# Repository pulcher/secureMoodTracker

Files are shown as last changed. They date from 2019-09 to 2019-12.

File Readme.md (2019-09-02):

# Secure Mood Tracker

## Purpose

To win a contest? [insert link to Hackster.io contest]

Not really.  Well, maybe?  It certainly was the initiating incident for this project.  

The project is an example of how to not only obtain telemetry data with an MT3620 based Azure Sphere device, but also how to consume and visualize the data in an extremly secure manner.

The project will track the mood of the office and report it to the cloud for further analysis.  

The project will have the following features:

* Display inviting a passer by to indicate their current mood by pressing one of 3 buttons.
* Good: Press the Green button.
* Average: Press the Yellow button.
* Bad(less than average, etc...): Press the Red button.
* The buttons will flash randomly to attrack attention
* There will be a proximity detector on the device to detect when there is motion in front of the device.  That way we can have some sort of data of how many times a person was in range of the device and a button was or was not pushed.
* Current temperature and humidity.  (Current IoT international by laws mandate this type of measurement.)
* Will also provide any other builtin sensor data that may be useful when the data is further analyzed.

## Design Considerations

* Must be created using the Azure Sphere MT3620 Starter Kit <https://www.element14.com/community/community/designcenter/azure-sphere-starter-kits>
* Device must be secure from end to end.

## Challenges

There are several challenges in this design.

### Not enough GPIO on the dev board

There are a number of GPIO pins on the Azure Sphere module, most of them are not directly accessible.

The dev board is setup to use the mikroBUS Click Modules.  It has a number of buttons, LEDS, Grove connectors, and more that consume most if not all of the easily available GPIO pins.

I have decided to solve that problem with the addition of a MCP23017 GPIO extender.  This gives me and additional 16 pins of GPIO, which is way more than required.

There is a Click module that holds MCP23017, I decided that using a generica module would be a more educational experience.  

There is a also a problem with libraries to access the expanded GPIO.  They don't currently exist in the Azure Sphere eco system.  There are libraries for the Click module using the Avent development system, but none specifically for the Azure Sphere module.

I the development board team has provided a reference application that accesses the various I2C modules on the dev board.  I plan on using that as a pattern to build up my own libarary to operate the MCP23017 over I2C.

### Attracking people to the device

The lights in the buttons can be controlled independently of the switch activation.  The lights will flash in various patterns to attract attention.

The device will be placed in a high traffic area.

The display will rotate with with data and instructions.

When the proximity sensor goes active the instructions will be display.

## Requirements

### Software

* Azure subscription
* Visual Studio 2019 Community Edition
* See the startup stuff...

### Hardware

* MT3620 Developement Board
* Red LED Mini Arcade Button http://adafru.it/3430
* Yellow LED Mini Arcade Button http://adafru.it/3430
* Green LED Mini Arcade Button http://adafru.it/3430
* MCP23017 breakout board
* 3 x 2N222 NPN transistors
* 3 x 220 ohm resistors
* USB Micro b jack to USB micro b plug http://adafru.it/5217
* Mini breadboard
* 3D printed case
* Power supply withe a micro b connector

### Tools

* Soldering Iron
* Digital Multimeter
* Jumper wires

## Build

### Software Setup

### Setup the MT3620

### Prep the buttons

### Connect up the MCP23017

### Connect the Oled

### Main code

### Print the enclosure

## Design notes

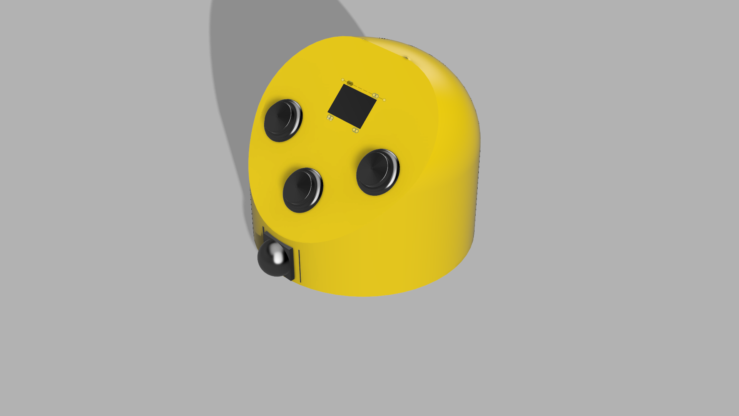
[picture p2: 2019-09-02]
Case Designs/c v2.png

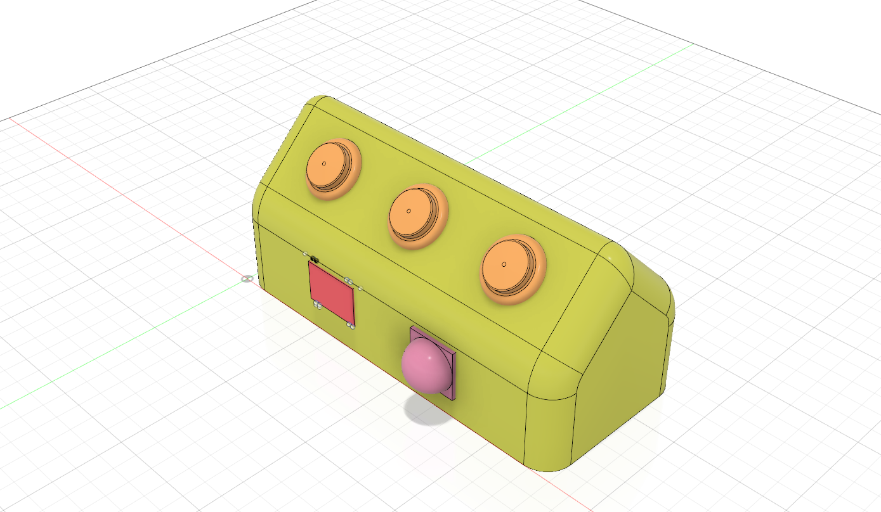
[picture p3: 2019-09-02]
Case Designs/b v2.png

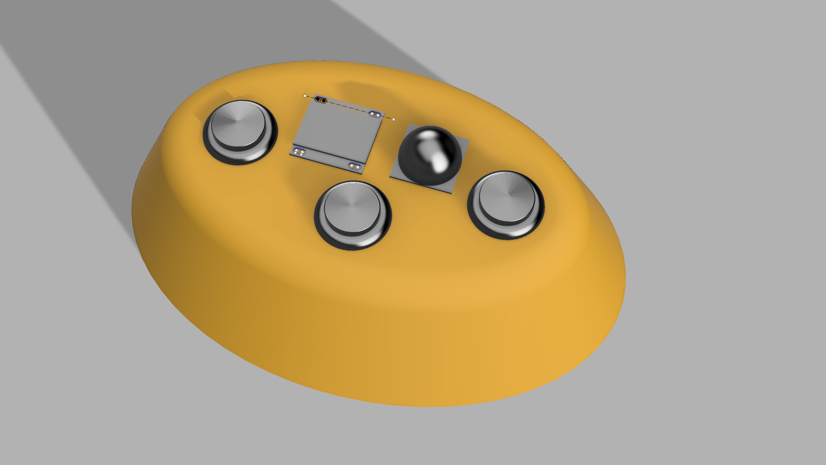
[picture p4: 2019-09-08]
Case Designs/f v1.png

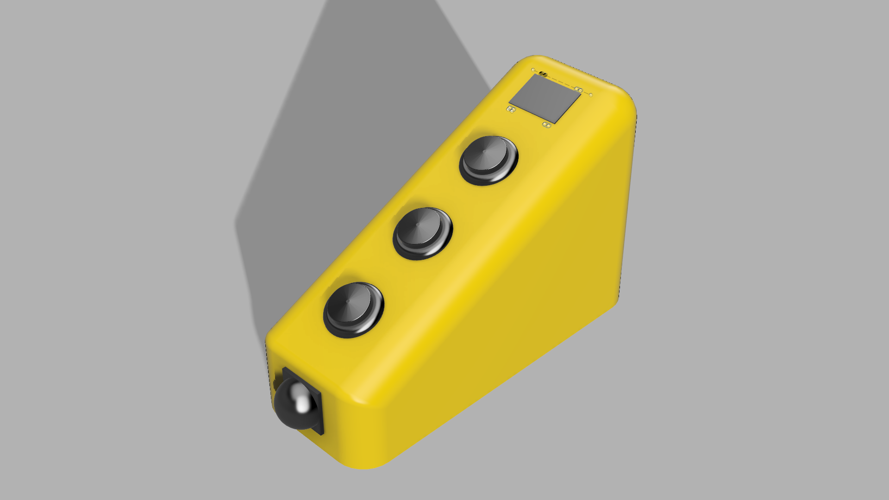
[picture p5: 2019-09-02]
Case Designs/d v2.png

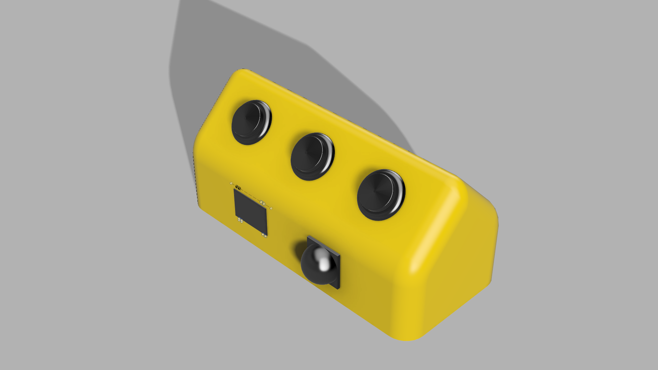
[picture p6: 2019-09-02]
Case Designs/b v3.png

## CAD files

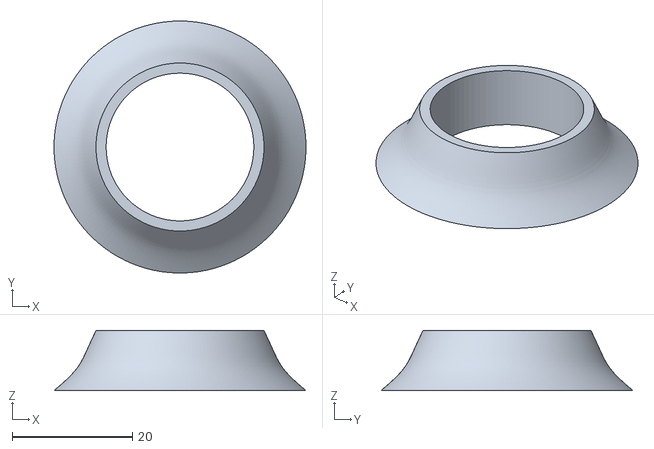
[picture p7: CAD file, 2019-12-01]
3D Models/button-riser.stl
42.0 x 42.0 x 10.0

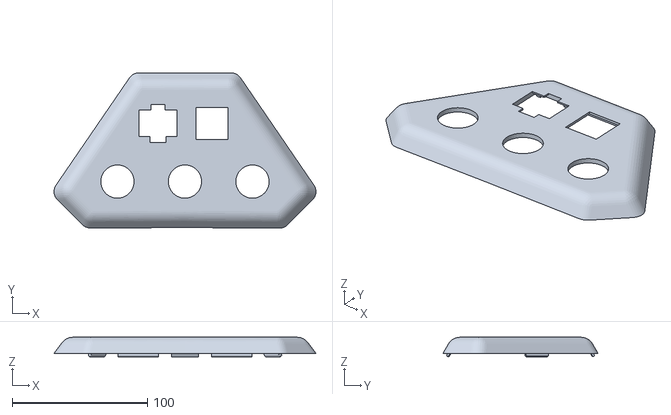
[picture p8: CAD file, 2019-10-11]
3D Models/top.stl
194.0 x 114.9 x 14.5

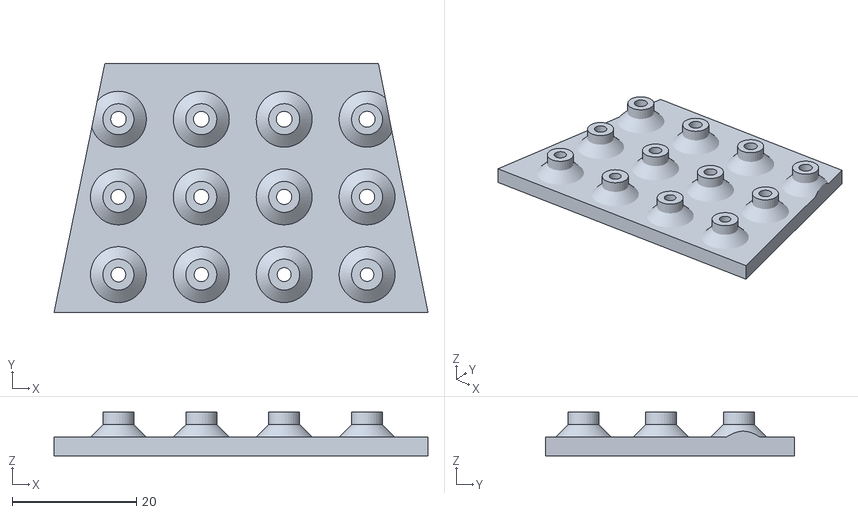
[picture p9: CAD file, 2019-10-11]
3D Models/2-5mm hole test.stl
60.2 x 40.1 x 7.00

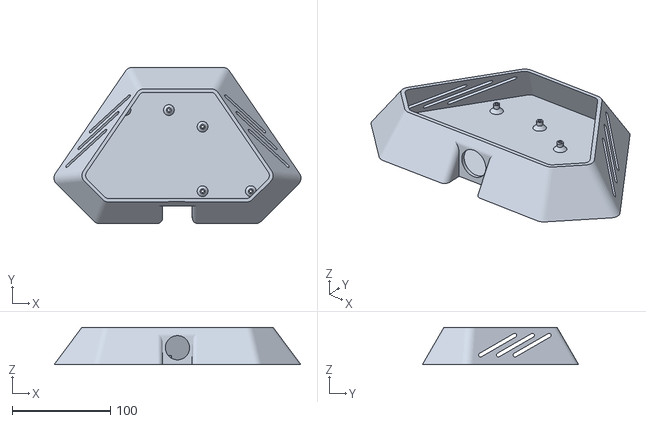
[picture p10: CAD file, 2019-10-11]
3D Models/bottom.stl
250.8 x 158.9 x 38.0

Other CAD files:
3D Models/2-5mm hole test 2.stl

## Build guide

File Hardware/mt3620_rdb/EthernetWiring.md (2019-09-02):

# Connecting Ethernet adapters to the MT3620 development board

This section provides instructions for connecting the following Ethernet boards and modules to the Azure Sphere MT3620 board.

- [Connection instructions for the Olimex ENC28J60-H development board](#Connection-instructions-for-the-Olimex-ENC28J60-H-development-board)
- [Connection instructions for the MT3620 Ethernet Shield](#Connection-instructions-for-the-MT3620-Ethernet-Shield)

***
## Connection instructions for the Olimex ENC28J60-H development board 
The [Olimex ENC28J60-H development board](https://www.olimex.com/Products/Modules/Ethernet/ENC28J60-H/) uses ISU port 0 (ISU0) to communicate with the MT3620 board via SPI.

 Use jumper wires to make the following connections between the ENC28J60-H board and the MT3620 board.

- ENC28J60-H 3V3: 10 to MT3620 3V3: Header 3 (upper right) Pin 3
- ENC28J60-H GND: 9 to MT3620 GND: Header 2 (lower left) Pin 2
- ENC28J60-H CS: 7 to MT3620 CSA0: Header 2 (lower left) Pin 1
- ENC28J60-H SCK: 1 to MT3620 SCLK0: Header 2 (lower left) Pin 3
- ENC28J60-H MOSI: 2 to MT3620 MOSI0: Header 2 (lower left) Pin 5
- ENC28J60-H MISO: 3 to MT3620 MISO0 RTS: Header 2 (lower left) Pin 7
- ENC28J60-H INT: 5 to MT3620 GPIO5: Header 2 (lower left) Pin 4

Refer to the following graphic for details.

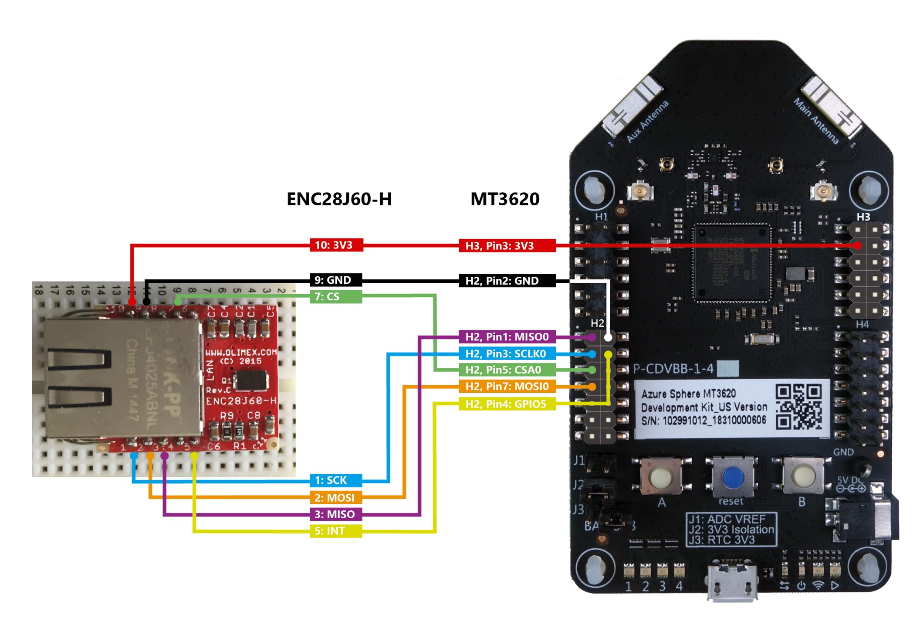
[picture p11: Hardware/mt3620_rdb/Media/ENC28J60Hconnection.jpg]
Connection diagram for ENC28J60-H and MT3620


***
## Connection instructions for the MT3620 Ethernet Shield 
The [MT3620 Ethernet Shield](https://www.seeedstudio.com/MT3620-Ethernet-Shield-v1-0-p-2917.html) uses the same board configuration package, and is internally wired to the same MT3620 development board GPIO pins as the Olimex ENC28J60-H Development Board.
It also uses the same ISU port (ISU0) to communicate with the MT3620 board via SPI. However, you connect the MT3620 Ethernet Shield directly to the interface headers on the MT3620 board.

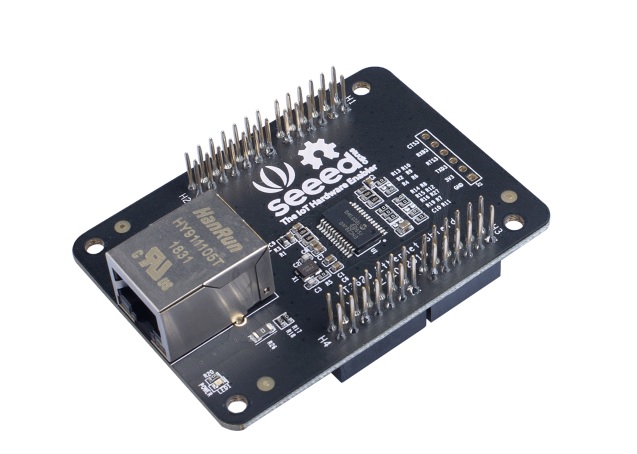
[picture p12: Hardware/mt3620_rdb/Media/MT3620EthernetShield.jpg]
MT3620 Ethernet Shield - Seeed Studio


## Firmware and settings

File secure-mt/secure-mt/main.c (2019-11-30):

#include <signal.h>
#include <stdbool.h>
#include <errno.h>
#include <string.h>
#include <time.h>
#include <stdio.h>
#include <stdarg.h>

#include "applibs_versions.h"
#include <applibs/gpio.h>
#include <applibs/log.h>
#include <applibs/networking.h>
#include <applibs/storage.h>

#include <hw/sample_hardware.h>

#include "build_options.h"

// Polling helpers
#include "epoll_timerfd_utilities.h"

// I2C connected sensors/modules
#include "i2c.h";
#include "mcp23x17.h";
#include "oled.h"
#include "lsm6dso_reg.h"
#include "lps22hh_reg.h"

// Azure IoT SDK
#include <iothub_client_core_common.h>
#include <iothub_device_client_ll.h>
#include <iothub_client_options.h>
#include <iothubtransportmqtt.h>
#include <iothub.h>
#include <azure_sphere_provisioning.h>

static volatile sig_atomic_t terminationRequired = false;

// Azure IoT Hub/Central stuff
#define SCOPEID_LENGTH 20
static char scopeId[SCOPEID_LENGTH]; // ScopeId for the Azure IoT Central application, set in
									 // app_manifest.json, CmdArgs
static IOTHUB_DEVICE_CLIENT_LL_HANDLE iothubClientHandle = NULL;
static bool iothubAuthenticated = false;
static const int keepalivePeriodSeconds = 20;

static void SendTelemetry(const unsigned char* key, const unsigned char* value);
static void SendMessageCallback(IOTHUB_CLIENT_CONFIRMATION_RESULT result, void* context);
static const char* GetReasonString(IOTHUB_CLIENT_CONNECTION_STATUS_REASON reason);
static const char* getAzureSphereProvisioningResultString(AZURE_SPHERE_PROV_RETURN_VALUE provisioningResult);

// Initialization/Cleanup
static int InitPeripheralsAndHandlers(void);
static void ClosePeripheralsAndHandlers(void);

// File descriptors - initialized to invalid value
// Buttons
static int sendMessageButtonGpioFd = -1;
static int sendOrientationButtonGpioFd = -1;

// Timer / polling
static int buttonPollTimerFd = -1;
static int azureTimerFd = -1;
static int epollFd = -1;

// Azure IoT poll periods
static const int AzureIoTDefaultPollPeriodSeconds = 5;
static const int AzureIoTMinReconnectPeriodSeconds = 5;
static const int AzureIoTMaxReconnectPeriodSeconds = 1 * 60;

static int azureIoTPollPeriodSeconds = -1;

// Statistics
static int voteCount = 0;
static float voteTotal = 0.0;
static float currentMood = 0.0;  // 2.0 is the meh value.  So, it is biased +2 for average reporting.
static int motionCount = -1;

static bool needScreenUpdate = true;	// we need to update the screen at least once. :)

// Button state variables
#define IDX_GREEN_BTN 0
#define IDX_YELLOW_BTN 1
#define IDX_RED_BTN 2
#define IDX_PROXIMITY 3

#define GREEN_VOTE 3
#define YELLOW_VOTE 2
#define RED_VOTE 1

#define NUM_INPUT_TRACKING 4

#define GREEN_ELEMENT_NAME "HappyButton"
#define YELLOW_ELEMENT_NAME "MehButton"
#define RED_ELEMENT_NAME "MadButton"
#define PROXIMITY_ELEMENT_NAME "ProximityAlert"

struct InputState {
	char ElementName[20];
	int Vote;
	int State;
};

struct InputState previousInputState[NUM_INPUT_TRACKING] = {
	{GREEN_ELEMENT_NAME, 3, 0},
	{YELLOW_ELEMENT_NAME, 2, 0},
	{RED_ELEMENT_NAME, 1, 0},
	{PROXIMITY_ELEMENT_NAME, 0, 0}
};

struct InputState currentInputState[NUM_INPUT_TRACKING] = {
	{GREEN_ELEMENT_NAME, 3, 0},
	{YELLOW_ELEMENT_NAME, 2, 0},
	{RED_ELEMENT_NAME, 1, 0},
	{PROXIMITY_ELEMENT_NAME, 0, 0}
};

static GPIO_Value_Type sendMessageButtonState = GPIO_Value_High;

static void ButtonPollTimerEventHandler(EventData* eventData);
static bool IsButtonPressed(int fd, GPIO_Value_Type* oldState);
static void SendMessageButtonHandler(void);
static void AzureTimerEventHandler(EventData* eventData);
static void RetainPreviousState();
static void UpdateCurrentState();
static void HandleInput(int index, int isButton);
static void UpdatePasserByCount();
static void UpdateMood(int index);

// event handler data structures. Only the event handler field needs to be populated.
static EventData buttonPollEventData = { .eventHandler = &ButtonPollTimerEventHandler };
static EventData azureEventData = { .eventHandler = &AzureTimerEventHandler };

/// <summary>
///     Signal handler for termination requests. This handler must be async-signal-safe.
/// </summary>
static void TerminationHandler(int signalNumber)
{
	// Don't use Log_Debug here, as it is not guaranteed to be async-signal-safe.
	terminationRequired = true;
}

int main(int argc, char* argv[])
{
	Log_Debug("IoT Hub/Central Application starting.\n");

	if (argc == 2) {
		Log_Debug("Setting Azure Scope ID %s\n", argv[1]);
		strncpy(scopeId, argv[1], SCOPEID_LENGTH);
	}
	else {
		Log_Debug("ScopeId needs to be set in the app_manifest CmdArgs\n");
		return -1;
	}

	// Fire up the timer and the Event Handlers
	if (InitPeripheralsAndHandlers() != 0) {
		//terminationRequired = true;
	}

	// Main loop
	while (!terminationRequired) {
		if (WaitForEventAndCallHandler(epollFd) != 0) {
			terminationRequired = true;
		}
	}

	ClosePeripheralsAndHandlers();

	Log_Debug("Application exiting.\n");

	return 0;
}

/// <summary>
///     Set up SIGTERM termination handler, initialize peripherals, and set up event handlers.
/// </summary>
/// <returns>0 on success, or -1 on failure</returns>
static int InitPeripheralsAndHandlers(void)
{
	struct sigaction action;
	memset(&action, 0, sizeof(struct sigaction));
	action.sa_handler = TerminationHandler;
	sigaction(SIGTERM, &action, NULL);

	epollFd = CreateEpollFd();
	if (epollFd < 0) {
		return -1;
	}

	// Open button A GPIO as input
	Log_Debug("Opening SAMPLE_BUTTON_1 as input\n");
	sendMessageButtonGpioFd = GPIO_OpenAsInput(SAMPLE_BUTTON_1);
	if (sendMessageButtonGpioFd < 0) {
		Log_Debug("ERROR: Could not open button A: %s (%d).\n", strerror(errno), errno);
		return -1;
	}

	// Open button B GPIO as input
	Log_Debug("Opening SAMPLE_BUTTON_2 as input\n");
	sendOrientationButtonGpioFd = GPIO_OpenAsInput(SAMPLE_BUTTON_2);
	if (sendOrientationButtonGpioFd < 0) {
		Log_Debug("ERROR: Could not open button B: %s (%d).\n", strerror(errno), errno);
		return -1;
	}

	// Set up a timer to poll for button events.
	struct timespec buttonPressCheckPeriod = { 0, 1000 * 1000 };
	buttonPollTimerFd =
		CreateTimerFdAndAddToEpoll(epollFd, &buttonPressCheckPeriod, &buttonPollEventData, EPOLLIN);
	if (buttonPollTimerFd < 0) {
		return -1;
	}

	// initialize the I2C master
	// - need pull ups?
	// - need status indicators for guard code
	initI2c();
	if (i2cFd < 0) {
		Log_Debug("ERROR: Could not open I2C master: %s (%d).\n", strerror(errno), errno);
		return -1;
	}

	// initialize the OLED screen
		// Start OLED
	if (oled_init())
	{
		Log_Debug("OLED not found!\n");
	}
	else
	{
		Log_Debug("OLED found!\n");
	}

	// Draw AVNET logo
	oled_draw_logo();
	oled_i2c_bus_status(0, currentMood, voteCount, motionCount);

	// initialize the MCP23017
	// - Port A input from buttons and proximity
	// - Port B output to button LEDS
	//
	// - No need for interrupts as we are polling at every 0.001 seconds.
	// - set port a with all pull-up resistors
	// - output can be high, as we are going through transistors to power the lights.
	mcp23x17_init(&i2cFd, 0);

	bool mcp23x17Detected = false;
	int failCount = 10;
	int32_t resultCheck = -1;

	while (!mcp23x17Detected) {
		// Check if mcp23x17Detected is connected
		resultCheck = mcp23x17_device_id_get(&mcp23x17_ctx, &whoami);

		if ((resultCheck < 0) || (whoami != MCP23X17_DEFAULT_HIGH)) {
			Log_Debug("resultCheck: %d\n", resultCheck);
			Log_Debug("whoami: %0x\n", whoami);
		}
		if (resultCheck < 0) {
			Log_Debug("MCP23x17 not found!\n");

			mcp23x17_status = 1;
		}
		else {
				mcp23x17Detected = true;
				Log_Debug("MCP23X17 Found!\n");

				mcp23x17_status = 0;

				// add setup code here
				uint8_t setOuputBank = 0x00U;
				mcp23x17_write_reg(&mcp23x17_ctx, MCP23017_IODIRB, &setOuputBank, 1);

				uint8_t testRead = 0xffU;

				uint8_t test = mcp23x17_read_reg(&mcp23x17_ctx, MCP23017_IODIRB, &testRead, 1);

				Log_Debug("test: %d\n", test);
				Log_Debug("testRead: %0x\n", testRead);

				// Setup default lights
				uint8_t testOutput = 0x07U;

				ssize_t writeRet = mcp23x17_write_reg(&mcp23x17_ctx, MCP23017_GPIOB, &testOutput, 1);

				uint8_t readRet = mcp23x17_read_reg(&mcp23x17_ctx, MCP23017_GPIOB, &testRead, 1);
				Log_Debug("readRet: %d\n", readRet);
				Log_Debug("testRead: %0x\n", testRead);

				// Setup the input buttons
				uint8_t baseInputState = 0xffU;  // this is the default, but I am making sure
				writeRet = mcp23x17_write_reg(&mcp23x17_ctx, MCP23017_IODIRA, &baseInputState, 1);
				writeRet = mcp23x17_write_reg(&mcp23x17_ctx, MCP23017_GPPUA, &baseInputState, 1);

				readRet = mcp23x17_read_reg(&mcp23x17_ctx, MCP23017_GPIOA, &testRead, 1);

				Log_Debug("readRet(portA): %d\n", readRet);
				Log_Debug("testRead(portA): %0x\n", testRead);
		}

		// If we failed to detect the mcp23x17Detected device, then pause before trying again.
		if (!mcp23x17Detected) {
			HAL_Delay(100);
		}

		if (failCount-- == 0) {
			Log_Debug("Failed to read mcp23x17 device ID.\n");
			return -1;
		}
	}

	// initialize the temp and humidity

	// lps22hh specific init

	bool lps22hhDetected = false;
	failCount = 10;

	while (!lps22hhDetected) {

		// Enable pull up on master I2C interface.
		lsm6dso_sh_pin_mode_set(&dev_ctx, LSM6DSO_INTERNAL_PULL_UP);

		// Check if LPS22HH is connected to Sensor Hub
		lps22hh_device_id_get(&pressure_ctx, &whoami);
		if (whoami != LPS22HH_ID) {
			Log_Debug("LPS22HH not found!\n");
		}
		else {
			lps22hhDetected = true;
			Log_Debug("LPS22HH Found!\n");
		}

		// Restore the default configuration
		lps22hh_reset_set(&pressure_ctx, PROPERTY_ENABLE);
		do {
			lps22hh_reset_get(&pressure_ctx, &rst);
		} while (rst);

		// Enable Block Data Update
		lps22hh_block_data_update_set(&pressure_ctx, PROPERTY_ENABLE);

		//Set Output Data Rate
		lps22hh_data_rate_set(&pressure_ctx, LPS22HH_10_Hz_LOW_NOISE);

		// If we failed to detect the lps22hh device, then pause before trying again.
		if (!lps22hhDetected) {
			HAL_Delay(100);
		}

		if (failCount-- == 0) {
			Log_Debug("Failed to read LSM22HH device ID, exiting\n");
			return -1;
		}
	}

	// may need to pump the i2c stuff through a single reader/writer
	// maybe make a symaphore for the longer periodic and write stuff
	// to limit the fast polling

	azureIoTPollPeriodSeconds = AzureIoTDefaultPollPeriodSeconds;
	struct timespec azureTelemetryPeriod = { azureIoTPollPeriodSeconds, 0 };
	azureTimerFd =
		CreateTimerFdAndAddToEpoll(epollFd, &azureTelemetryPeriod, &azureEventData, EPOLLIN);
	if (buttonPollTimerFd < 0) {
		return -1;
	}

	return 0;
}

/// <summary>
///     Sets the IoT Hub authentication state for the app
///     The SAS Token expires which will set the authentication state
/// </summary>
static void HubConnectionStatusCallback(IOTHUB_CLIENT_CONNECTION_STATUS result,
	IOTHUB_CLIENT_CONNECTION_STATUS_REASON reason,
	void* userContextCallback)
{
	iothubAuthenticated = (result == IOTHUB_CLIENT_CONNECTION_AUTHENTICATED);
	Log_Debug("IoT Hub Authenticated: %s\n", GetReasonString(reason));
}

/// <summary>
///     Sets up the Azure IoT Hub connection (creates the iothubClientHandle)
///     When the SAS Token for a device expires the connection needs to be recreated
///     which is why this is not simply a one time call.

/// </summary>


static void SetupAzureClient(void)
{
	if (iothubClientHandle != NULL)
		IoTHubDeviceClient_LL_Destroy(iothubClientHandle);

	AZURE_SPHERE_PROV_RETURN_VALUE provResult =
		IoTHubDeviceClient_LL_CreateWithAzureSphereDeviceAuthProvisioning(scopeId, 10000,
			&iothubClientHandle);
	Log_Debug("IoTHubDeviceClient_LL_CreateWithAzureSphereDeviceAuthProvisioning returned '%s'.\n",
		getAzureSphereProvisioningResultString(provResult));

	if (provResult.result != AZURE_SPHERE_PROV_RESULT_OK) {

		// If we fail to connect, reduce the polling frequency, starting at
		// AzureIoTMinReconnectPeriodSeconds and with a backoff up to
		// AzureIoTMaxReconnectPeriodSeconds
		if (azureIoTPollPeriodSeconds == AzureIoTDefaultPollPeriodSeconds) {
			azureIoTPollPeriodSeconds = AzureIoTMinReconnectPeriodSeconds;
		}
		else {
			azureIoTPollPeriodSeconds *= 2;
			if (azureIoTPollPeriodSeconds > AzureIoTMaxReconnectPeriodSeconds) {
				azureIoTPollPeriodSeconds = AzureIoTMaxReconnectPeriodSeconds;
			}
		}

		struct timespec azureTelemetryPeriod = { azureIoTPollPeriodSeconds, 0 };
		SetTimerFdToPeriod(azureTimerFd, &azureTelemetryPeriod);

		Log_Debug("ERROR: failure to create IoTHub Handle - will retry in %i seconds.\n",
			azureIoTPollPeriodSeconds);
		return;
	}

	// Successfully connected, so make sure the polling frequency is back to the default
	azureIoTPollPeriodSeconds = AzureIoTDefaultPollPeriodSeconds;
	struct timespec azureTelemetryPeriod = { azureIoTPollPeriodSeconds, 0 };
	SetTimerFdToPeriod(azureTimerFd, &azureTelemetryPeriod);

	iothubAuthenticated = true;

	if (IoTHubDeviceClient_LL_SetOption(iothubClientHandle, OPTION_KEEP_ALIVE,
		&keepalivePeriodSeconds) != IOTHUB_CLIENT_OK) {
		Log_Debug("ERROR: failure setting option \"%s\"\n", OPTION_KEEP_ALIVE);
		return;
	}

	//IoTHubDeviceClient_LL_SetDeviceTwinCallback(iothubClientHandle, TwinCallback, NULL);
	IoTHubDeviceClient_LL_SetConnectionStatusCallback(iothubClientHandle,
		HubConnectionStatusCallback, NULL);
}

/// <summary>
///     Converts the IoT Hub connection status reason to a string.
/// </summary>
static const char* GetReasonString(IOTHUB_CLIENT_CONNECTION_STATUS_REASON reason)
{
	static char* reasonString = "unknown reason";
	switch (reason) {
	case IOTHUB_CLIENT_CONNECTION_EXPIRED_SAS_TOKEN:
		reasonString = "IOTHUB_CLIENT_CONNECTION_EXPIRED_SAS_TOKEN";
		break;
	case IOTHUB_CLIENT_CONNECTION_DEVICE_DISABLED:
		reasonString = "IOTHUB_CLIENT_CONNECTION_DEVICE_DISABLED";
		break;
	case IOTHUB_CLIENT_CONNECTION_BAD_CREDENTIAL:
		reasonString = "IOTHUB_CLIENT_CONNECTION_BAD_CREDENTIAL";
		break;
	case IOTHUB_CLIENT_CONNECTION_RETRY_EXPIRED:
		reasonString = "IOTHUB_CLIENT_CONNECTION_RETRY_EXPIRED";
		break;
	case IOTHUB_CLIENT_CONNECTION_NO_NETWORK:
		reasonString = "IOTHUB_CLIENT_CONNECTION_NO_NETWORK";
		break;
	case IOTHUB_CLIENT_CONNECTION_COMMUNICATION_ERROR:
		reasonString = "IOTHUB_CLIENT_CONNECTION_COMMUNICATION_ERROR";
		break;
	case IOTHUB_CLIENT_CONNECTION_OK:
		reasonString = "IOTHUB_CLIENT_CONNECTION_OK";
		break;
	}
	return reasonString;
}

/// <summary>
///     Converts AZURE_SPHERE_PROV_RETURN_VALUE to a string.
/// </summary>
static const char* getAzureSphereProvisioningResultString(
	AZURE_SPHERE_PROV_RETURN_VALUE provisioningResult)
{
	switch (provisioningResult.result) {
	case AZURE_SPHERE_PROV_RESULT_OK:
		return "AZURE_SPHERE_PROV_RESULT_OK";
	case AZURE_SPHERE_PROV_RESULT_INVALID_PARAM:
		return "AZURE_SPHERE_PROV_RESULT_INVALID_PARAM";
	case AZURE_SPHERE_PROV_RESULT_NETWORK_NOT_READY:
		return "AZURE_SPHERE_PROV_RESULT_NETWORK_NOT_READY";
	case AZURE_SPHERE_PROV_RESULT_DEVICEAUTH_NOT_READY:
		return "AZURE_SPHERE_PROV_RESULT_DEVICEAUTH_NOT_READY";
	case AZURE_SPHERE_PROV_RESULT_PROV_DEVICE_ERROR:
		return "AZURE_SPHERE_PROV_RESULT_PROV_DEVICE_ERROR";
	case AZURE_SPHERE_PROV_RESULT_GENERIC_ERROR:
		return "AZURE_SPHERE_PROV_RESULT_GENERIC_ERROR";
	default:
		return "UNKNOWN_RETURN_VALUE";
	}
}

/// <summary>
///     Close peripherals and handlers.
/// </summary>
static void ClosePeripheralsAndHandlers(void)
{
	Log_Debug("Closing file descriptors\n");

	//// Leave the LEDs off
	//if (deviceTwinStatusLedGpioFd >= 0) {
	//	GPIO_SetValue(deviceTwinStatusLedGpioFd, GPIO_Value_High);
	//}

	CloseFdAndPrintError(buttonPollTimerFd, "ButtonTimer");
	CloseFdAndPrintError(azureTimerFd, "AzureTimer");
	CloseFdAndPrintError(sendMessageButtonGpioFd, "SendMessageButton");
	//CloseFdAndPrintError(sendOrientationButtonGpioFd, "SendOrientationButton");
	//CloseFdAndPrintError(deviceTwinStatusLedGpioFd, "StatusLed");
	CloseFdAndPrintError(epollFd, "Epoll");
	CloseFdAndPrintError(i2cFd, "I2C");
}

/*
 * Handlers
 */

 /// <summary>
 ///     Check whether a given button has just been pressed.
 /// </summary>
 /// <param name="fd">The button file descriptor</param>
 /// <param name="oldState">Old state of the button (pressed or released)</param>
 /// <returns>true if pressed, false otherwise</returns>
static bool IsButtonPressed(int fd, GPIO_Value_Type* oldState)
{
	bool isButtonPressed = false;
	GPIO_Value_Type newState;
	int result = GPIO_GetValue(fd, &newState);
	if (result != 0) {
		Log_Debug("ERROR: Could not read button GPIO: %s (%d).\n", strerror(errno), errno);
		terminationRequired = true;
	}
	else {
		// Button is pressed if it is low and different than last known state.
		isButtonPressed = (newState != *oldState) && (newState == GPIO_Value_Low);
		*oldState = newState;
	}

	return isButtonPressed;
}

/// <summary>
/// Pressing button A will:
///     Send a 'Button Pressed' event to Azure IoT Central
/// </summary>
static void SendMessageButtonHandler(void)
{
	if (IsButtonPressed(sendMessageButtonGpioFd, &sendMessageButtonState)) {
		Log_Debug("Button pressed\n");
		SendTelemetry("ButtonPress", "True");
	}
}

/// <summary>
/// IsInputStateChanged(index)
/// Compare the state of the input and report back whether the state has changed from the last time checked
/// </summary>
static bool IsInputStateChanged(int index)
{
	bool changed = currentInputState[index].State != previousInputState[index].State;
	return changed;
}

/// <summary>
/// UpdateButtonLED
/// Read the current state of the input and update the LEDS of the buttons.
/// </summary>
static void UpdateButtonLED()
{
	uint8_t buttonState = 0x007;

	if (currentInputState[0].State)
		buttonState = buttonState & 0x06U;  // bit 0

	if (currentInputState[1].State)
		buttonState = buttonState & 0x05U;  // bit 1

	if (currentInputState[2].State)
		buttonState = buttonState & 0x03U;  // bit 2

	ssize_t writeRet = mcp23x17_write_reg(&mcp23x17_ctx, MCP23017_GPIOB, &buttonState, 1);
}

/// <summary>
/// UpdateMood(index) will increment the vote and re-calculate the current mood.
/// will also set that the display needs to be updated.
/// </summary>
static void UpdateMood(int vote)
{
	voteTotal += vote;
	voteCount += 1.0;
	currentMood = voteTotal/voteCount;

	needScreenUpdate = true;

	Log_Debug("Vote Count: %f, Vote Total: %f, Current Mood: %f\n", voteCount, voteTotal, currentMood);
}

/// <summary>
/// UpdatePasserByCount() will increment the number of people seen.
/// </summary>
static void UpdatePasserByCount()
{
	motionCount++;

	needScreenUpdate = true;

	Log_Debug("Passer by count: %f\n", motionCount);
}

/// <summary>
/// Updates the current status of the input
/// - checks if the state is changed
/// - updates LED output to reflect the state
/// - updates the vote totals
/// - send message on low input (button press)
/// <summary>
static void HandleInput(int index, int isButton)
{
	if (!IsInputStateChanged(index))
		return;

	UpdateButtonLED();	// will read the current state and update the lights.

	if (currentInputState[index].State) {
		//updateTotals(currentInputState[index].Vote);
		Log_Debug("Button Pressed: %s.\n", currentInputState[index].ElementName);
		SendTelemetry(currentInputState[index].ElementName, "True");
	}
	else {
		Log_Debug("Button Released: %s.\n", currentInputState[index].ElementName);

		if (isButton) {
			UpdateMood(currentInputState[index].Vote);
		}
		else {
			UpdatePasserByCount();
		}
		SendTelemetry(currentInputState[index].ElementName, "False");
	}
}

/// <summary>
/// RetainPreviousState will copy the current button state to a previous for comparison
/// </summary>
static void RetainPreviousState()
{
	for (size_t i = 0; i < 4; i++)
	{
		previousInputState[i].State = currentInputState[i].State;
	}
}

/// <summary>
/// UpdateCurrentState will read the current input state then update the currentButtonState
/// to be used by the rest of the program
/// </summary>
static void UpdateCurrentState()
{
	uint8_t inputState = 0x00U;

	// grab the input byte from the MCP23017
	uint8_t readRet = mcp23x17_read_reg(&mcp23x17_ctx, MCP23017_GPIOA, &inputState, 1);

	uint8_t checkPosition = 0x01U;

	// Shift off the value of each of the bits into the correct position of the state
	for (size_t i = 0; i < 4; i++)
	{
		currentInputState[i].State = checkPosition & inputState ? 0 : 1;

		// move the checkPosition to what we care about
		checkPosition <<= 1;
	}
}

/// <summary>
/// Button timer event:  Check the status of buttons A and B
/// </summary>
static void ButtonPollTimerEventHandler(EventData* eventData)
{
	if (ConsumeTimerFdEvent(buttonPollTimerFd) != 0) {
		terminationRequired = true;
		return;
	}

	// test if the mcp is online and active
	// pull the port A from mcp23017
	if (!mcp23x17_status) {

		// break apart the bits
		RetainPreviousState();
		UpdateCurrentState();

		// Send in the array of structs that holds:
		// - state
		// - Message to send to Azure
		// - value to adjust the daily totals if any
		// - Element Name for Azure
		// -
		HandleInput(IDX_GREEN_BTN, 1);
		HandleInput(IDX_YELLOW_BTN, 1);
		HandleInput(IDX_RED_BTN, 1);
		HandleInput(IDX_PROXIMITY, 0);

		// for each in the array that is non-zero then send a message for each
		// proximity is just a funky button

		// update the screen with a thanks for each with a pause... probably should make that call async
		// maybe setup an array with the message and have the message pop up over the
	}

	oled_i2c_bus_status(0, currentMood, voteCount, motionCount);

	SendMessageButtonHandler();
}
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

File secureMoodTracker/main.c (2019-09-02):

/* Copyright (c) Microsoft Corporation. All rights reserved.
   Licensed under the MIT License. */

   /************************************************************************************************
   Name: AvnetStarterKitReferenceDesign
   Sphere OS: 19.05
   This file contains the 'main' function. Program execution begins and ends there

   Authors:
   Peter Fenn (Avnet Engineering & Technology)
   Brian Willess (Avnet Engineering & Technology)

   Purpose:
   Using the Avnet Azure Sphere Starter Kit demonstrate the following features

   1. Read X,Y,Z accelerometer data from the onboard LSM6DSO device using the I2C Interface
   2. Read X,Y,Z Angular rate data from the onboard LSM6DSO device using the I2C Interface
   3. Read the barometric pressure from the onboard LPS22HH device using the I2C Interface
   4. Read the temperature from the onboard LPS22HH device using the I2C Interface
   5. Read the state of the A and B buttons
   6. Read BSSID address, Wi-Fi AP SSID, Wi-Fi Frequency
   *************************************************************************************************
      Connected application features: When connected to Azure IoT Hub or IoT Central
   *************************************************************************************************
   7. Send X,Y,Z accelerometer data to Azure
   8. Send barometric pressure data to Azure
   9. Send button state data to Azure
   10. Send BSSID address, Wi-Fi AP SSID, Wi-Fi Frequency data to Azure
   11. Send the application version string to Azure
   12. Control user RGB LEDs from the cloud using device twin properties
   13. Control optional Relay Click relays from the cloud using device twin properties
   14. Send Application version up as a device twin property
   TODO
   1. Add support for a OLED display
   2. Add supprt for on-board light sensor

   *************************************************************************************************/

// TODO: update all of these comments when I get something working.

#include <errno.h>
#include <signal.h>
#include <stdbool.h>
#include <stdlib.h>
#include <string.h>
#include <time.h>
#include <unistd.h>
#include <stdio.h>
#include <math.h>

// applibs_versions.h defines the API struct versions to use for applibs APIs.
#include "applibs_versions.h"
#include "epoll_timerfd_utilities.h"
#include "i2c.h"
#include "mt3620_avnet_dev.h"
#include "deviceTwin.h"
#include "azure_iot_utilities.h"
#include "connection_strings.h"
#include "build_options.h"

#include <applibs/log.h>
#include <applibs/i2c.h>
#include <applibs/gpio.h>
#include <applibs/wificonfig.h>
#include <azureiot/iothub_device_client_ll.h>

//// OLED
#include "oled.h"

//// ADC connection
#include <sys/time.h>
#include <sys/socket.h>
#include <applibs/application.h>

// Provide local access to variables in other files
extern twin_t twinArray[];
extern int twinArraySize;
extern IOTHUB_DEVICE_CLIENT_LL_HANDLE iothubClientHandle;

// Support functions.
static void TerminationHandler(int signalNumber);
static int InitPeripheralsAndHandlers(void);
static void ClosePeripheralsAndHandlers(void);

// File descriptors - initialized to invalid value
int epollFd = -1;
static int buttonPollTimerFd = -1;
static int buttonAGpioFd = -1;
static int buttonBGpioFd = -1;

int userLedRedFd = -1;
int userLedGreenFd = -1;
int userLedBlueFd = -1;
int appLedFd = -1;
int wifiLedFd = -1;
int clickSocket1Relay1Fd = -1;
int clickSocket1Relay2Fd = -1;

//// ADC connection
static const char rtAppComponentId[] = "005180bc-402f-4cb3-a662-72937dbcde47";
static int sockFd = -1;
static void SendMessageToRTCore(void);
static void TimerEventHandler(EventData *eventData);
static void SocketEventHandler(EventData *eventData);
static int timerFd = -1;
uint8_t RTCore_status;

// event handler data structures. Only the event handler field needs to be populated.
static EventData timerEventData = { .eventHandler = &TimerEventHandler };
static EventData socketEventData = { .eventHandler = &SocketEventHandler };
//// end ADC connection

// Button state variables, initilize them to button not-pressed (High)
static GPIO_Value_Type buttonAState = GPIO_Value_High;
static GPIO_Value_Type buttonBState = GPIO_Value_High;

#if (defined(IOT_CENTRAL_APPLICATION) || defined(IOT_HUB_APPLICATION))
	bool versionStringSent = false;
#endif

// Define the Json string format for the accelerator button press data
static const char cstrButtonTelemetryJson[] = "{\"%s\":\"%d\"}";

// Termination state
volatile sig_atomic_t terminationRequired = false;

/// <summary>
///     Signal handler for termination requests. This handler must be async-signal-safe.
/// </summary>
static void TerminationHandler(int signalNumber)
{
    // Don't use Log_Debug here, as it is not guaranteed to be async-signal-safe.
    terminationRequired = true;
}
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

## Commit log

2019-09-02 added case designs and updated Readme.md
2019-09-02 getting the hang of this include file. need to use events to blink the LED
2019-09-02 added the button polling and timers
2019-09-02 got data going to iot central again. understand where I should put my button tracking code
2019-09-04 got the i2c initialized. next is the mcp23017
2019-09-09 the accelerometer/temparature is not responding, but should be. Gonna need to check this out.
2019-09-29 adding in the stl for printing
    [bottom.stl, top.stl]
2019-10-11 working up the oled messages
    [2-5mm hole test 2.stl, 2-5mm hole test.stl, bottom.stl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]
2019-11-10 got the box buttoned up and all the controls seem to be working as expected
2019-11-20 the buttons now work. lights don't follow though.:
2019-11-24 got the lights synced with the buttons
2019-12-01 just added in assests/pictures
    [button-riser.stl]
